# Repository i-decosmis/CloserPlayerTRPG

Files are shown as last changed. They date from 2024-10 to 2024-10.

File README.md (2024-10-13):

# CloserPlayerTRPG

<div align="center">

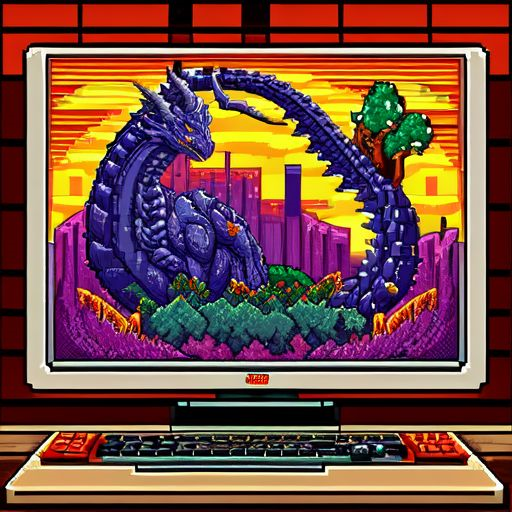
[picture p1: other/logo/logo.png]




</div>

# Introduction 🐉
This project aims to reduce the feeling of remoteness for people playing hybrid TRPGs online (some players in person and one online for now).
The basic idea is giving the remote player the opportunity to easily interact with the environment during the session.

The idea is to use a `client-server` application to remotely control a rotating platform, where a portable computer or tablet can be placed to display the remote player. 
The remote player can control the rotating platform from their computer. 
This concept is based on using a video-call communication app like Discord. 
This way, the remote player can look around and interact more effectively with others, while the in-person players can see his face throughout the session.

# Introduzione 🐉
Questo progetto mira a ridurre la sensazione di lontananza per le persone che giocano a TRPG ibridi online (con alcuni giocatori in presenza e uno online per ora).

L'idea di base è offrire al giocatore remoto la possibilità di interagire facilmente con l'ambiente durante la sessione.

L'idea è utilizzare un'applicazione client-server per controllare a distanza una piattaforma rotante, su cui può essere posizionato un computer portatile o un tablet per mostrare il giocatore remoto. Il giocatore remoto può controllare la piattaforma rotante dal proprio computer. Questo concetto si basa sull'uso di un'app di comunicazione video come Discord. In questo modo, il giocatore remoto può guardarsi intorno e interagire in modo più efficace con gli altri, mentre i giocatori in presenza possono vedere il suo volto per tutta la durata della sessione.

- [English version](guide/en/README.md)
- [Versione italiana](guide/it/README.md)

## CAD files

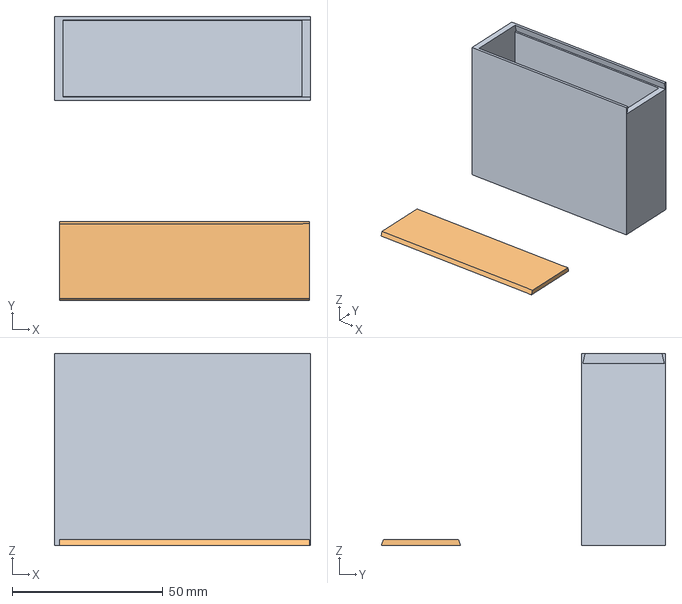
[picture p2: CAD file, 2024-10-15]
other/3D pieces/box.3mf
85.0 x 94.4 x 63.8 mm
box.stl
lid.stl

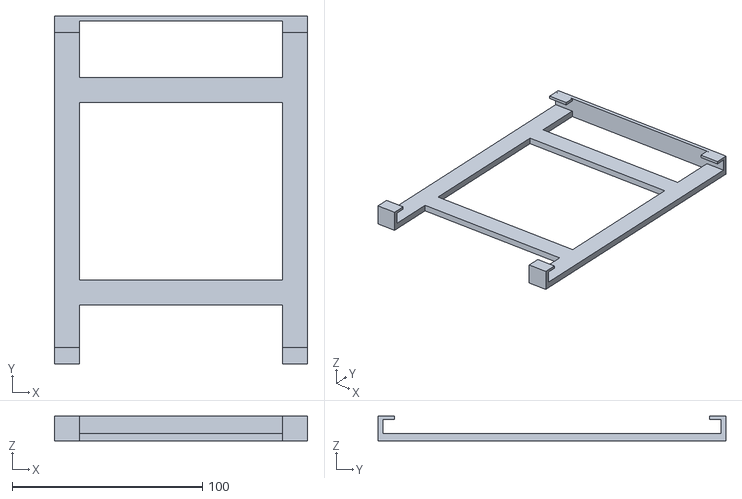
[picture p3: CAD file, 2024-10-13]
other/3D pieces/Structure.stl
133.1 x 183.1 x 13.0

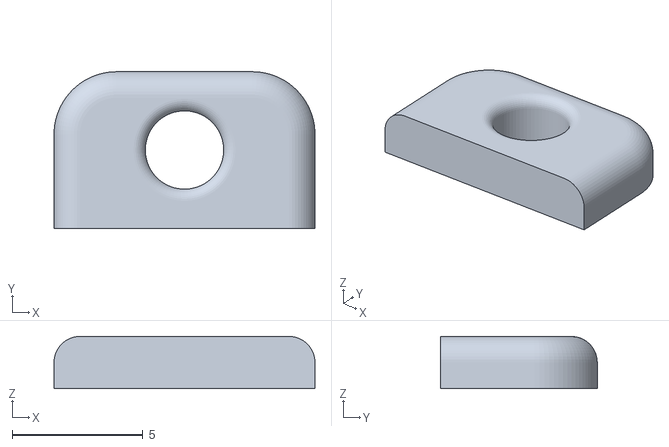
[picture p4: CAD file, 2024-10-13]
other/3D pieces/BoltHole.stl
10.0 x 6.00 x 2.00

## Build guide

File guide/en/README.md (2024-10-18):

# The basic architecture 🏗️
The server, placed on top of the rotating platform, will interact with an Arduino. This Arduino will control the platform's rotation.
The client will be used by the remote player to control the rotating platform.

# Software 💿

## Installation of Requirements 🔧
* Install Anaconda.
* Navigate in the `other/utils` folder.
* Run the following command: 
```bash
conda env create --file environment.yml --name CloserPlayerTRPG
```
* At the end of the installation activate the environment:
```bash
conda activate CloserPlayerTRPG
```

# Use the framework 📙
To use the framework, you can run the file directly from the console or generate an .exe file and run the generated executable.
## Run from console ⌨️
* Navigate in the `app` folder.
### Client 🖥️
* Navigate in the `client` folder.
* Run:
```bash
python client.py
```
### Server 🌐
* Navigate in the `server` folder.
* Run:
```bash
python server.py
```

## Exporting app for Windows
### Client 🖥️
* Navigate in the `app/client` folder.
* Run the following command:
```bash
pyinstaller --onefile --windowed client.py
```
* In the dist folder you can find the exe file of the client.

### Server 🌐
* Navigate in the `app/server` folder.
* Run the following command:
```bash
pyinstaller --onefile --windowed server.py
```
* In the dist folder you can find the exe file of the server.

# Hardware  🛠️
## Components used: 🎟️
* [Mcbazel - 360° Rotating Stand](https://www.amazon.it/dp/B09FZ36N3M?ref=ppx_yo2ov_dt_b_fed_asin_title).
* [Arduino Nano Clone](https://www.amazon.it/dp/B0CWH4P152?ref=ppx_yo2ov_dt_b_fed_asin_title).
* [Breadboard](https://www.amazon.it/dp/B078HV79XX?ref=ppx_yo2ov_dt_b_fed_asin_title).

## Steps 📋
### Adapting the Rotating Stand
* Remove the top lid:
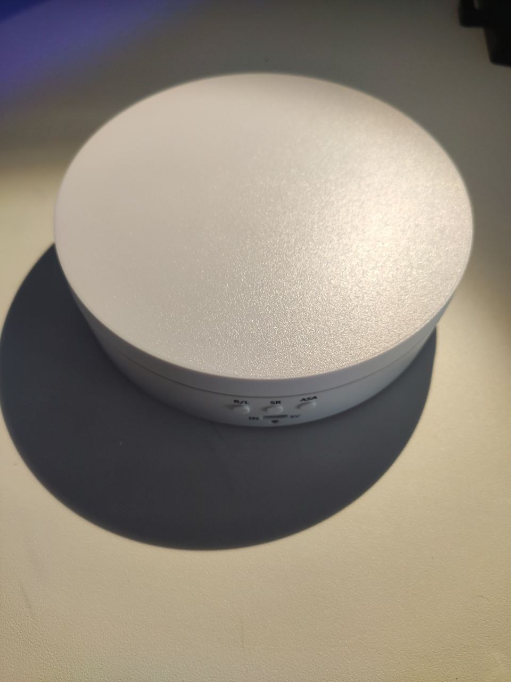
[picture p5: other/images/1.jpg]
One

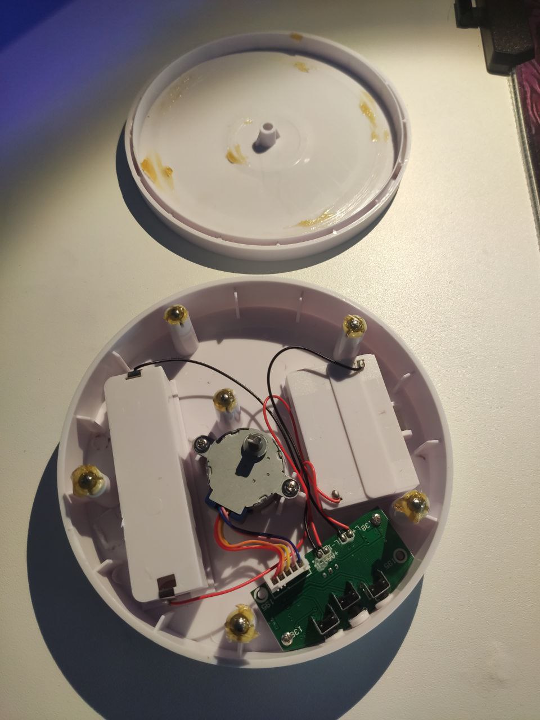
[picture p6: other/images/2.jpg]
Two


* Unplug the motor from the motherboard.
* Remove the motor and motherboard from the case, and cut the wires connected to the battery holders:
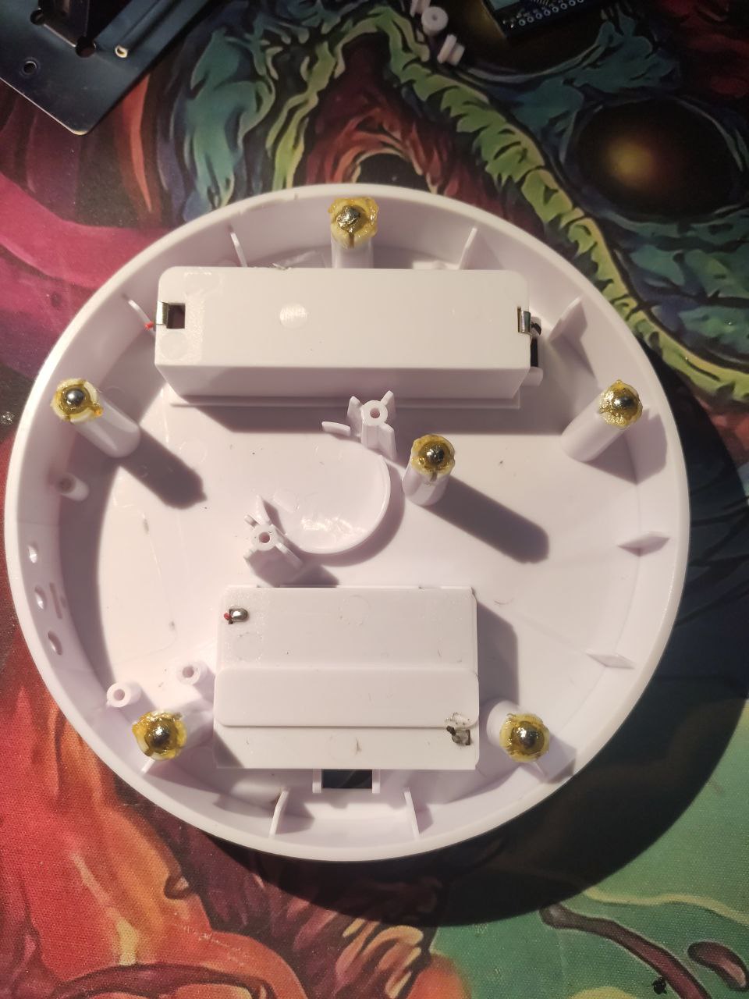
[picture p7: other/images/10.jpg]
Ten

* Cut the battery holders to create more space inside the case. I used my soldering iron for this:
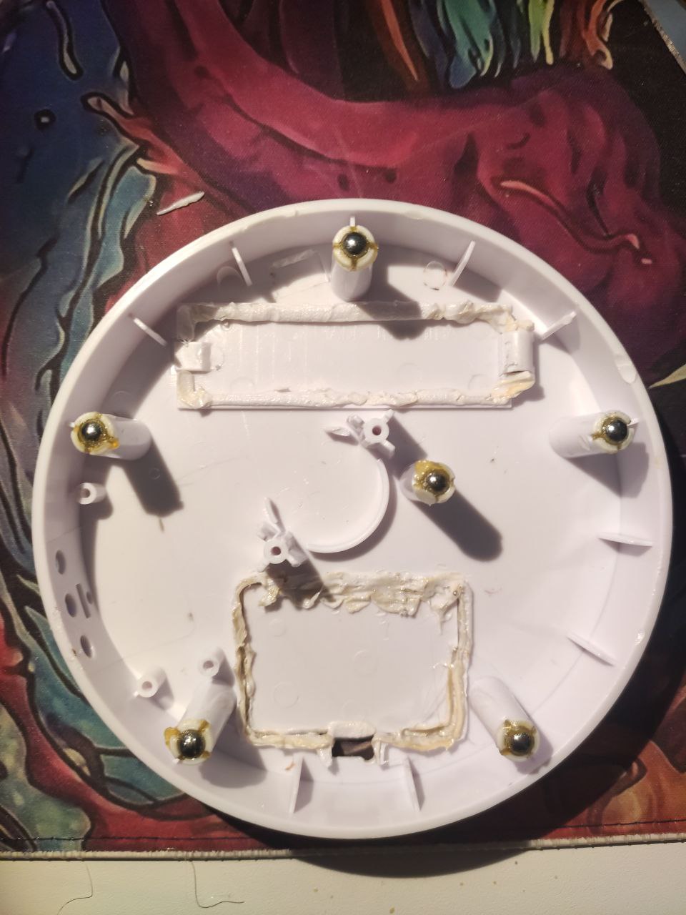
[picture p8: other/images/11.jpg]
Eleven


### Remove the useful components from the motherboard

* Cut the ULN2003 component and desolder the motor connector:
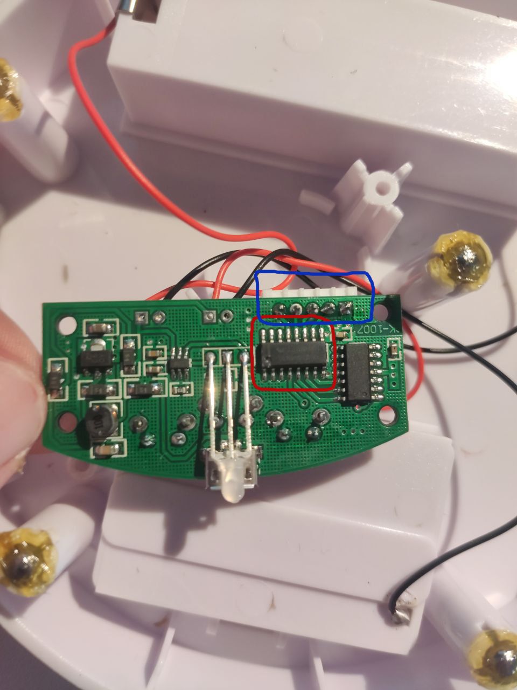
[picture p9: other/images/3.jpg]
Three

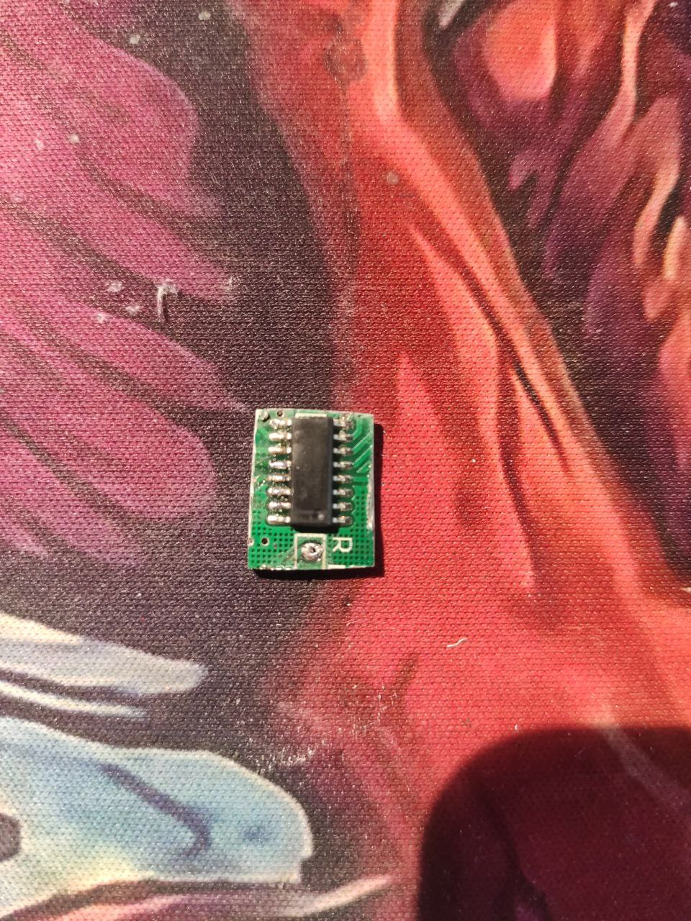
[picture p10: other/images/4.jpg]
Four


* Use double-sided tape to attach the removed component to the breadboard:
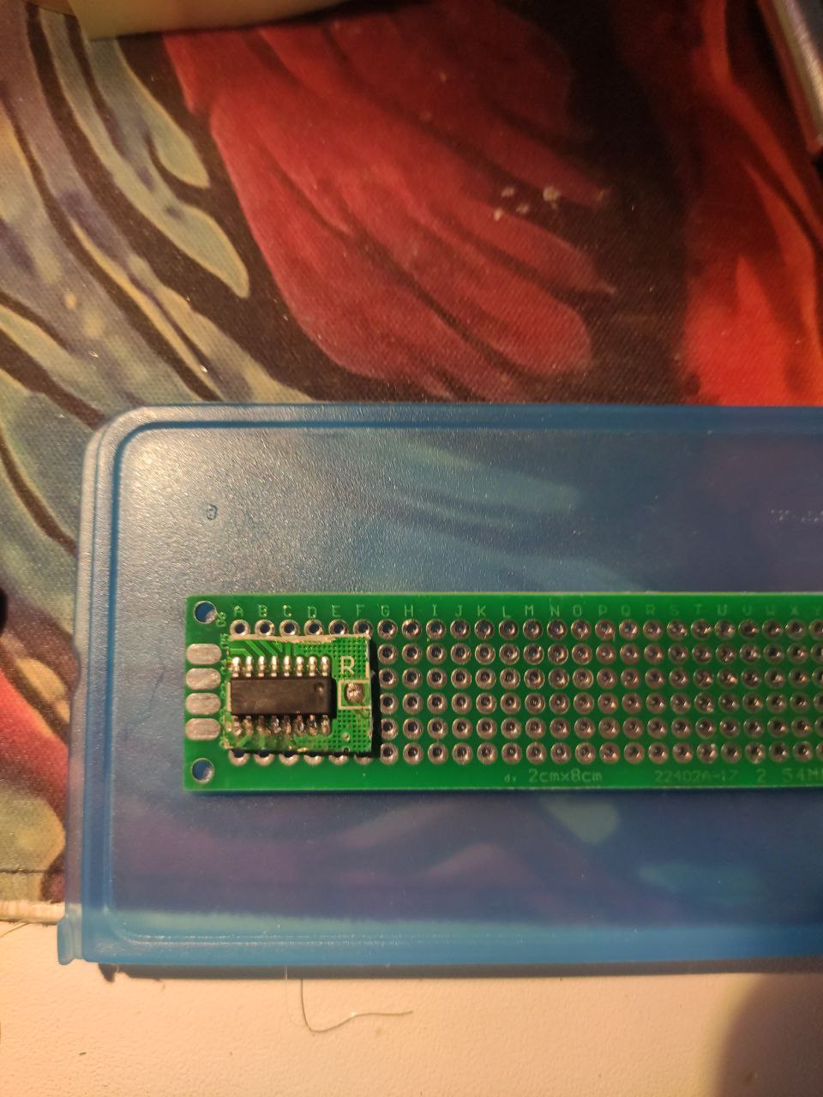
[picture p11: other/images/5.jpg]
Five


* Use a soldering iron to connect the ULN2003 to the motor connector, referring to the following schematic for guidance:
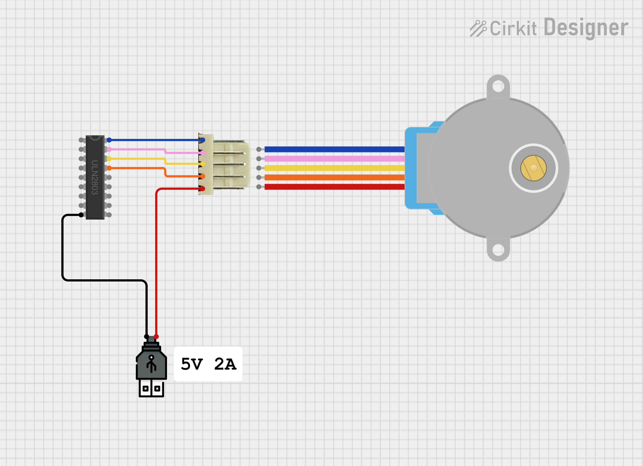
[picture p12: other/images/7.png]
Six

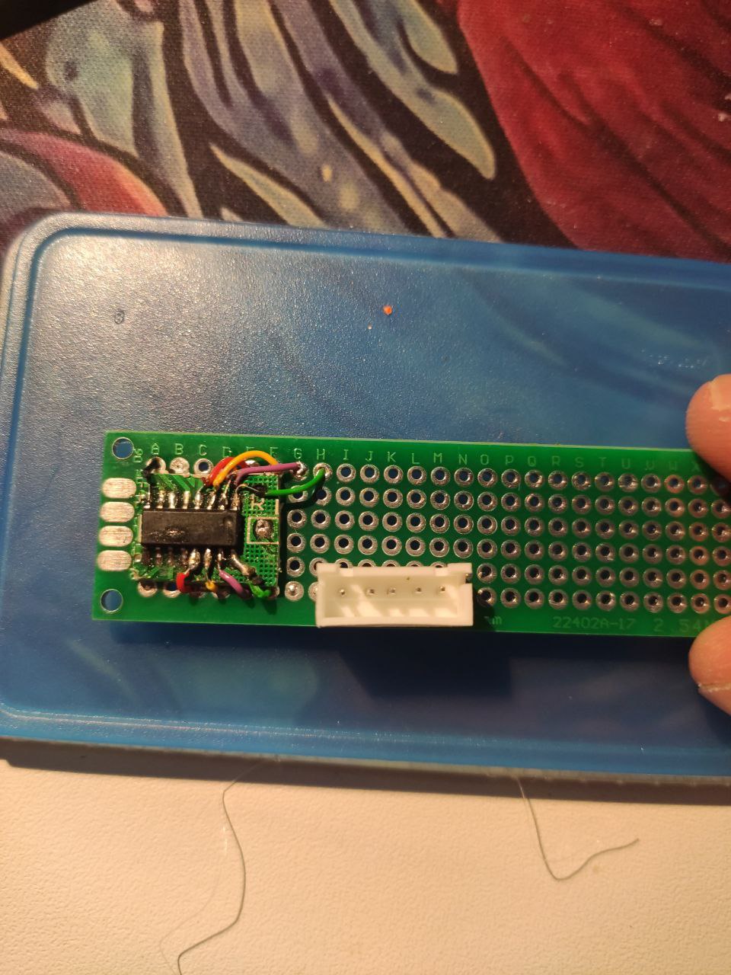
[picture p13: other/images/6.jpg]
Seven


* Use a soldering iron to connect the Arduino Nano to the ULN2003, referring to the following schemaric for guidance:
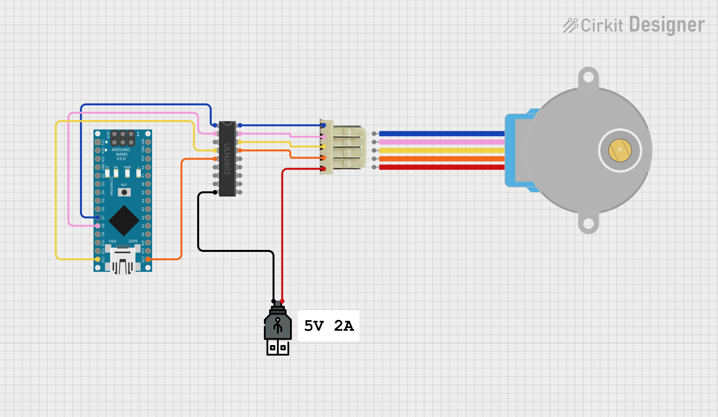
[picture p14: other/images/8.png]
Eight

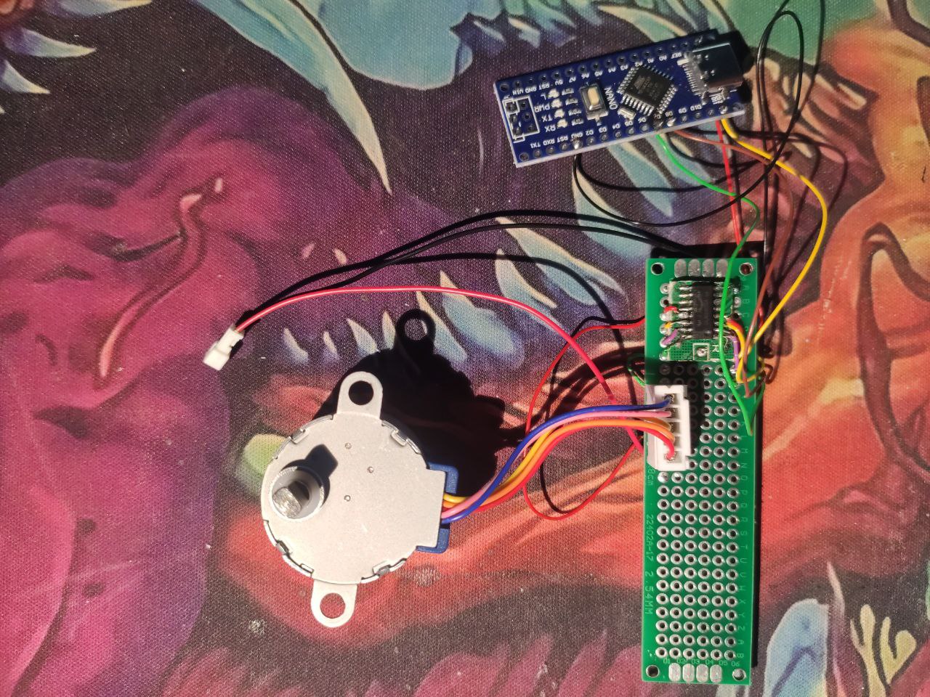
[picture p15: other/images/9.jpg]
Nine


* I inserted the components as shown in the image, using hot glue to fix them in place and using a male/female connector to be able to disconnect the 5V USB power supply if necessary:
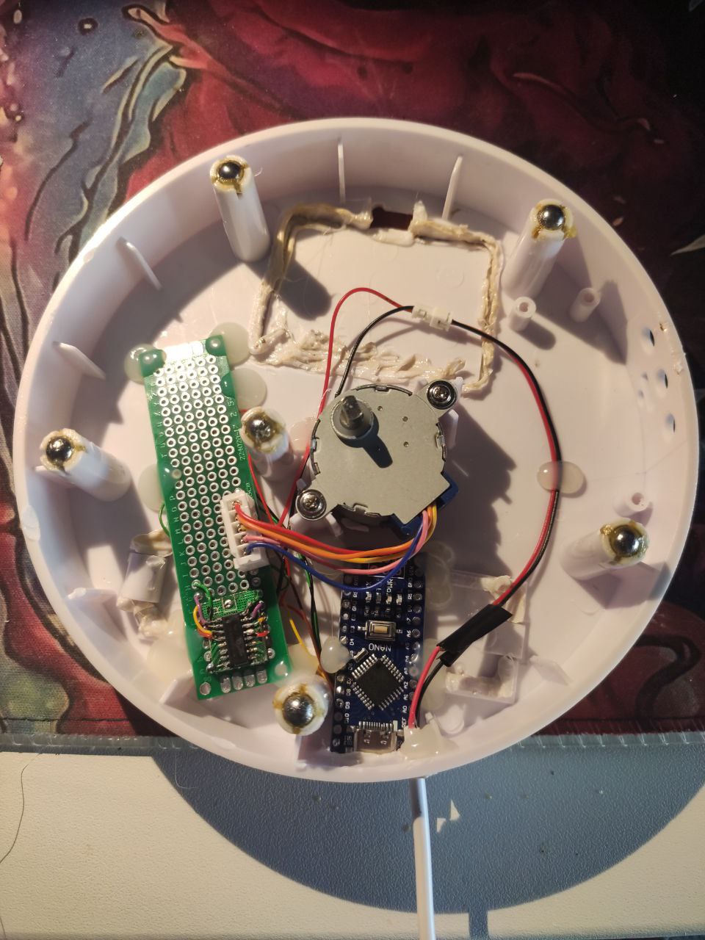
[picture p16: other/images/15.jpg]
Fifteen


### 3D print a tablet holder (optional)
* You can also use a portable PC, but for practical reasons, I chose to use a tablet. Therefore, I needed a structure to hold it.
The following models are available:
    * [Structure to hold the tablet](../../other/3D%20pieces/Structure.stl)
    * [Bolt holes](../../other/3D%20pieces/BoltHole.stl)

I've fused the two pieces togheter using a cyanoalicrate based glue.

* Results:
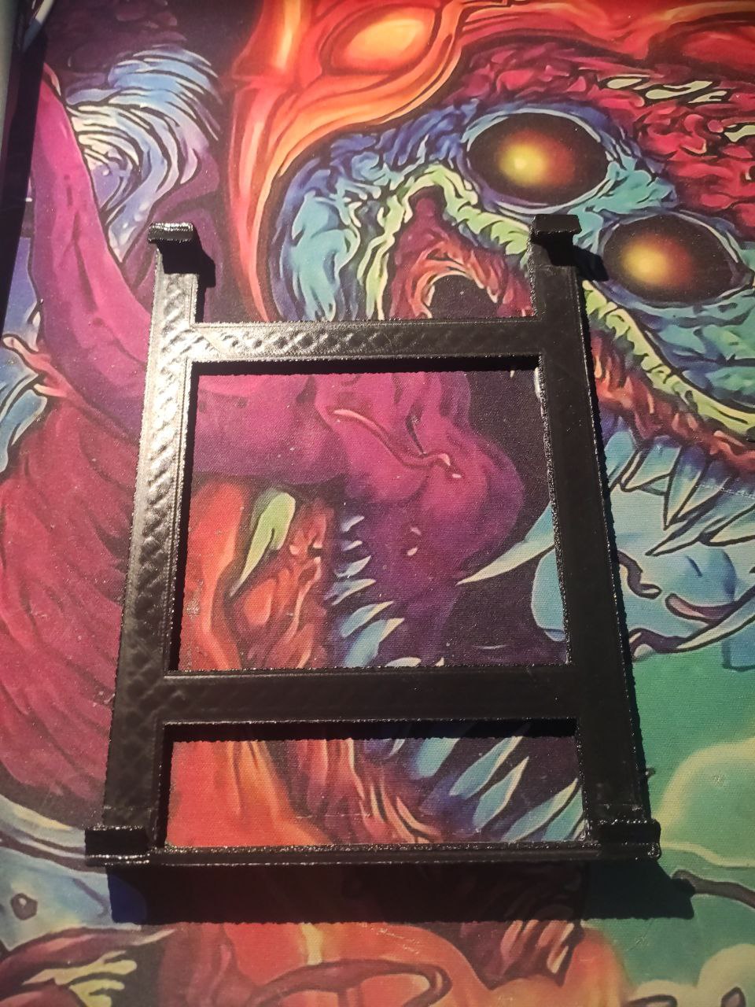
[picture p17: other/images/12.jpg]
Twelve

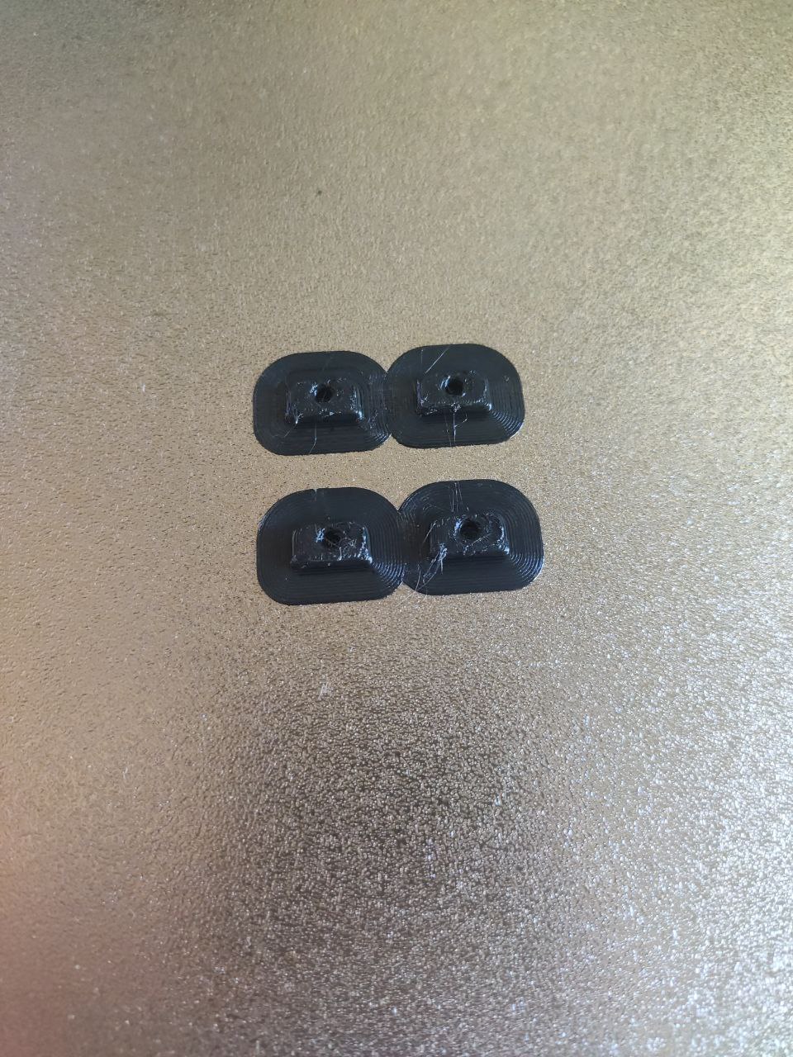
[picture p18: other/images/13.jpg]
Thirteen


* Using the iron solder I punctured the plate and with 4 bolts I connected the two pieces:
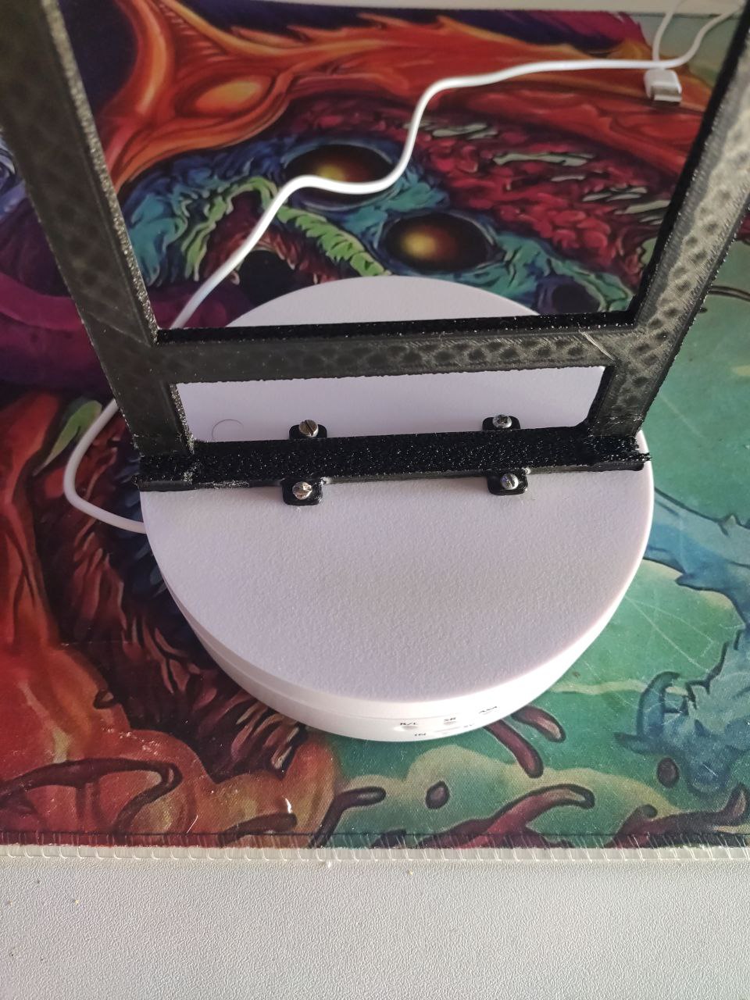
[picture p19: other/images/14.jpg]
Fourthen


### Final result
* Slide the tablet in the frame.
* I have used an externa webcam with integrated mic, I have also used a usb-c hub, hotglued to the back of the plane, to connet the cam and arduino to the tablet as show in the figures:
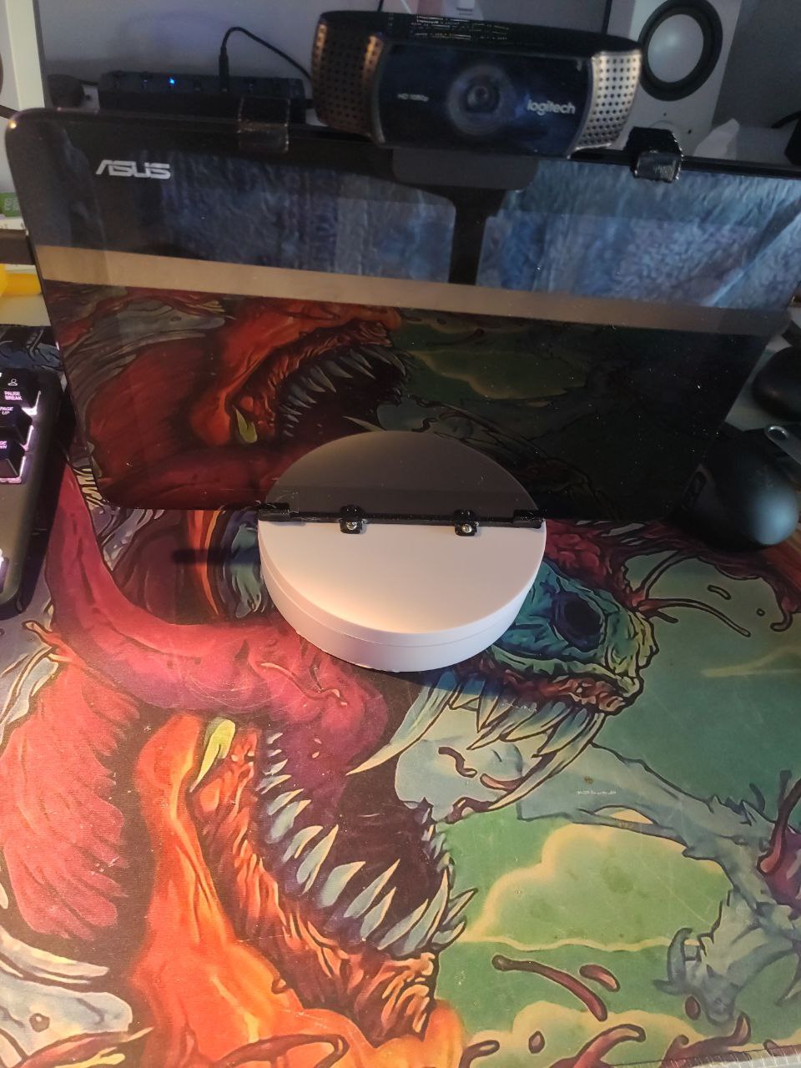
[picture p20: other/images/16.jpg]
Sixteen

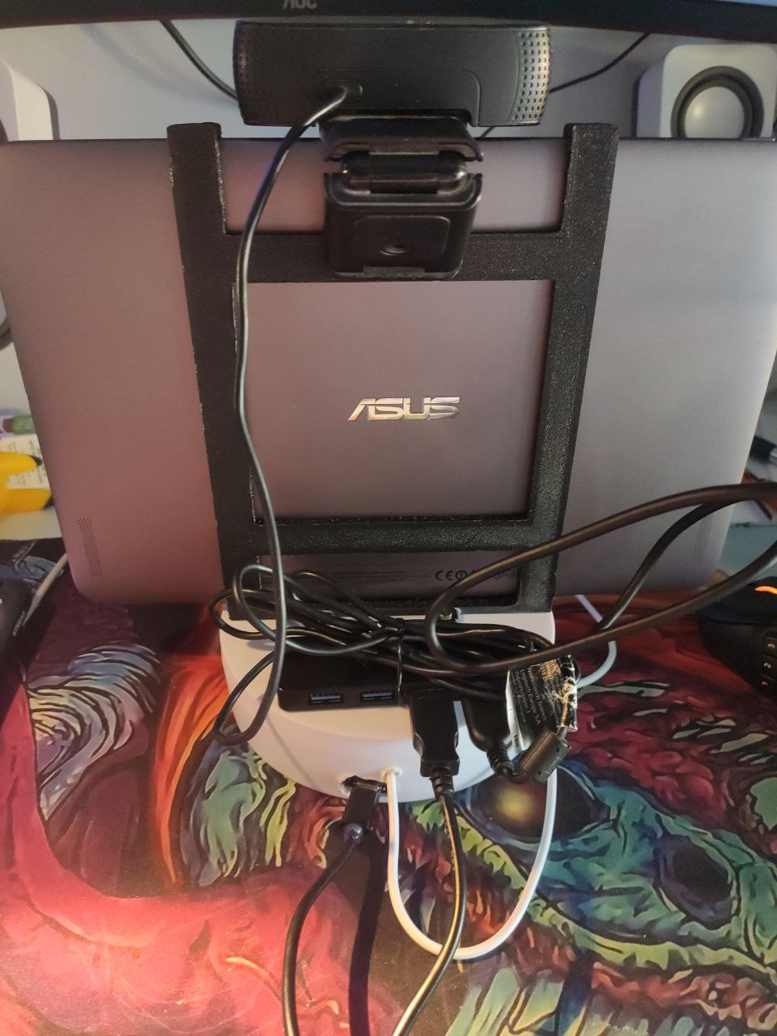
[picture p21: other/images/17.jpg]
Seventeen

This general schema represent the final result:
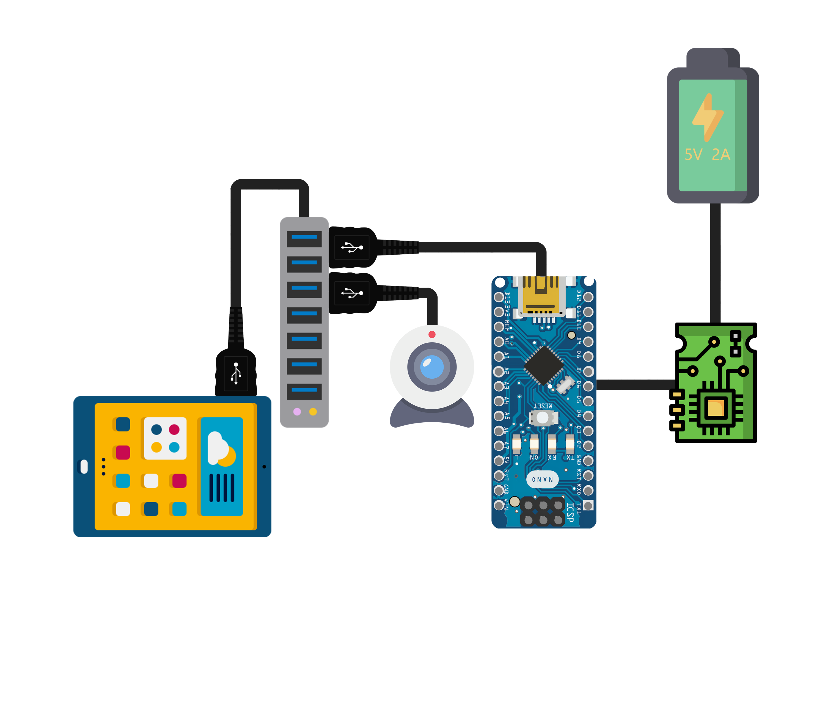
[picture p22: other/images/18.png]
Eighteen


### Improvements 📈
This improvements are optional but allow for a better cable management and practicality:
* I have 3d printed a [small box](../../other/3D%20pieces/box.3mf) to store all the cables inside.
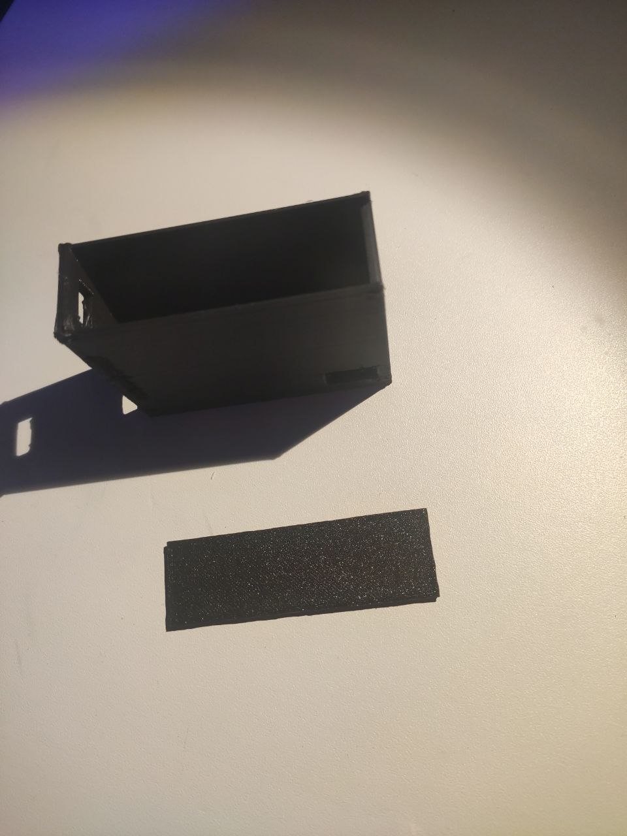
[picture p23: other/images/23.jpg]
Twentythree

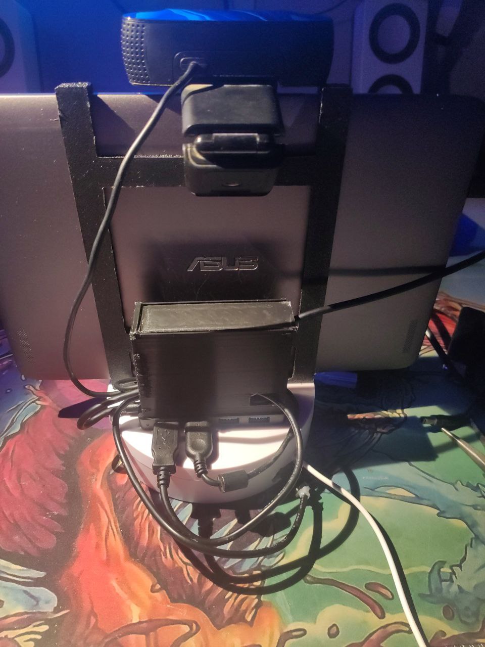
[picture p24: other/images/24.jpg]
Twentyfour


* My tablet can't stay on for the entire session, so it needs to be charged. To avoid adding more cables, I decided to change the power supply by using a [multi-USB 5V charger with two outputs rated at 5V and 3.1A](https://www.amazon.it/dp/B0D73DZ6QT?ref=ppx_yo2ov_dt_b_fed_asin_title). I soldered the two USB outputs together to power both the 28BYJ-48 motor and the tablet with a single cable.
* Updated general circuit:
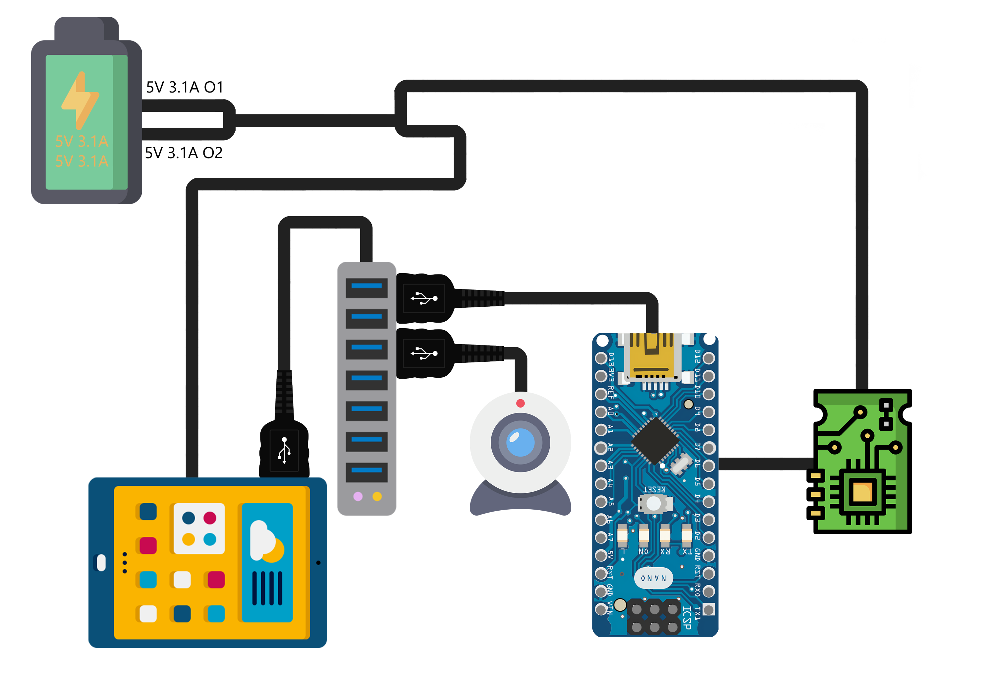
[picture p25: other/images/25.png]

Note: In my case, the tablet also needed the data pins to be connected, even though the cable is only used for charging.

* To achieve a cleaner front appearance, I also added a 90-degree connector to the USB-C hub and another 90-degree connector for the tablet's charging port.
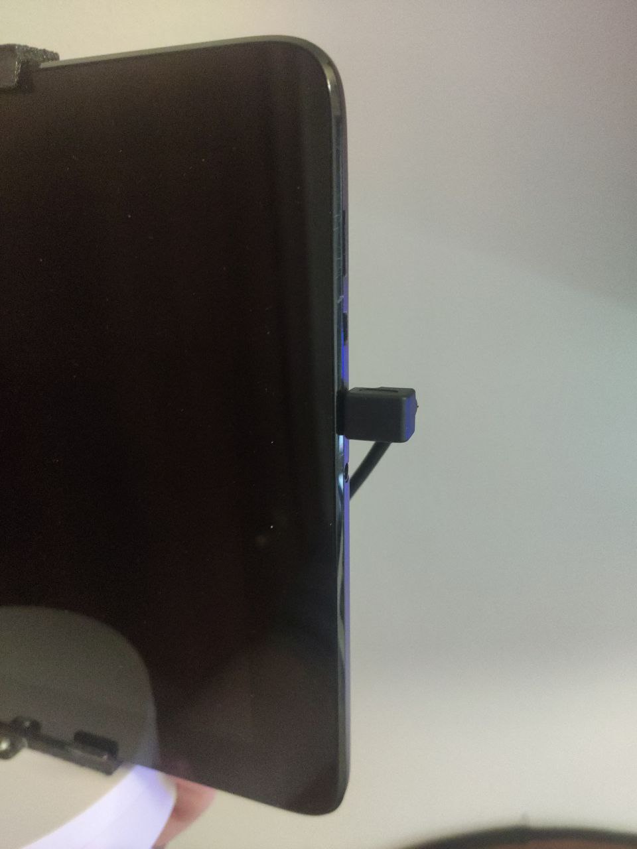
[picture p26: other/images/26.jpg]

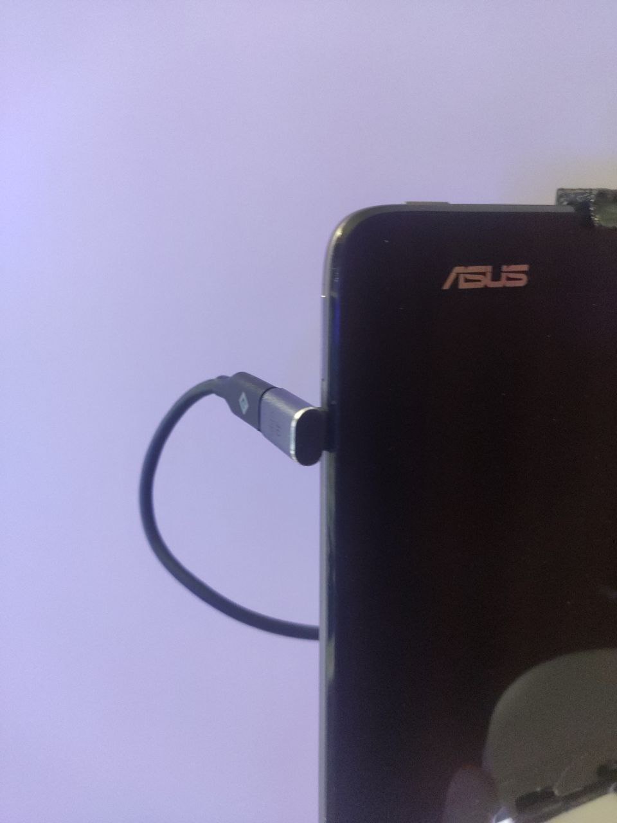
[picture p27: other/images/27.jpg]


# User Guide 📜
## Server 🌐
* Open the server.
* Insert the Ip Address and the port where to host the server, e.g. `127.0.0.1:5556`.
* Select in the top right the comunication port for arduino.
* Click `Start Server`.
* Wait for the client to connect.

## Client 🖥️
* Open the client.
* Insert the Ip Address and the port, e.g. `127.0.0.1:5556`.
* Click `Connect`.
* Once connected, the window will resize to a small frame where the selected input will be displayed.
* To send input, you must select the window first. If other applications are selected, the client will not detect the input.

## Router port ❌
To avoid opening router ports, use app like Tailscale or Hamachi.

### Example with Hamachi
* On the server pc:
    * Open Hamachi 
    * Create a new network, e.g. `CloserTest`:
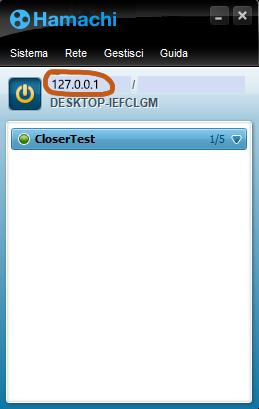
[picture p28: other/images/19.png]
Nineteen
    

    * Open the server application
    * Insert the highlighted Ip from your Hamachi and a port of your choise, e.g. `5556`.
    * Select on the top right the comunication port of the connected arduino:
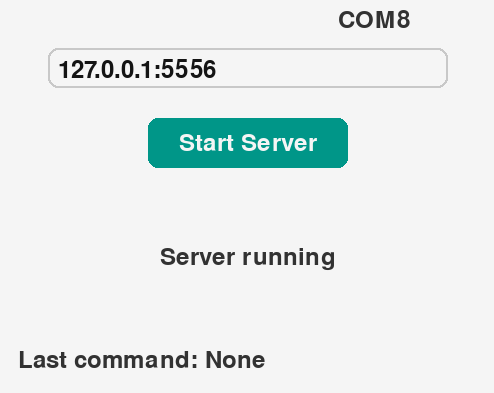
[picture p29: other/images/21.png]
Twentyone
    
    
    * Click `Start Server`
* On the client pc:
    * Open Hamachi.
    * Join the created network.
    * Open the client application.
    * Insert the Ip of the server pc and the port you choose during the server start (In this example `127.0.0.1:5556`).
    * Click `Connect`.
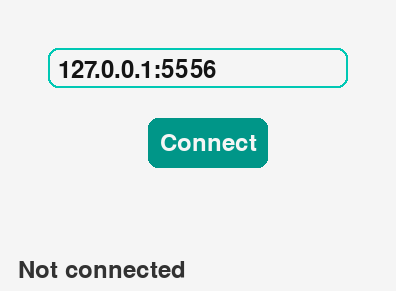
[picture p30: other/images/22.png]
Twentytwo
    

Now you can control the rotation of the arduino connected to the server with the client.
Using a voice chat app (like Discord), your friend playing remotely can move the tablet and look around, while everyone playing in person can see his face as he looks around!

# Issues 🆘
Nothing for now

# Future Ideas 💡
* Provide the remote player with the opportunity to physically roll a die using a robotic hand.
* Create "dances" that the platform can perform to allow the player to celebrate after a funny situation.
* 3d print a structure for vertical rotation.

# License 🛂
This project is licensed under the **GNU General Public License v3.0**. You are free to use, modify, and distribute this code under the following conditions:

1. **Attribution**: If you use this code as a base for your project or create derivative works, please give appropriate credit by including my name (Ivan De Cosmis) in your project documentation, README, or other relevant materials.

2. **Share-Alike**: Any derivative work you create based on this project must also be licensed under the GPLv3. This ensures that future users can benefit from your modifications as well.

3. **Commercial Use**: If you intend to use this project or any derivatives for commercial purposes, please reach out to me first to discuss proper attribution and any potential agreements.

For more details, please refer to the full text of the **GNU General Public License v3.0** [here](https://www.gnu.org/licenses/gpl-3.0.html).

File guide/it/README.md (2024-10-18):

# L'architettura di base 🏗️
Il server, posizionato sopra la piattaforma rotante, interagirà con un Arduino. Questo Arduino controllerà la rotazione della piattaforma.  
Il client sarà utilizzato dal giocatore remoto per controllare la piattaforma rotante.

# Software 💿

## Installazione dei requisiti 🔧
* Installa Anaconda.
* Vai nella cartella `other/utils`.
* Esegui il seguente comando:
```bash
conda env create --file environment.yml --name CloserPlayerTRPG
```
* Alla fine dell'installazione, attiva l'ambiente:
```bash
conda activate CloserPlayerTRPG
```

# Utilizzo del framework 📙
Per usare il framework, puoi eseguire il file direttamente dalla console o generare un file .exe ed eseguire l'eseguibile generato.
## Esecuzione da console ⌨️
* Vai nella cartella `app`.
### Client 🖥️
* Vai nella cartella `client`.
* Esegui:
```bash
python client.py
```
### Server 🌐
* Vai nella cartella `server`.
* Esegui:
```bash
python server.py
```

## Esportare l'app per Windows
### Client 🖥️
* Vai nella cartella `app/client`.
* Esegui il seguente comando:
```bash
pyinstaller --onefile --windowed client.py
```
* Nella cartella dist troverai il file exe del client.

### Server 🌐
* Vai nella cartella `app/server`.
* Esegui il seguente comando:
```bash
pyinstaller --onefile --windowed server.py
```
* Nella cartella dist troverai il file exe del server.

# Hardware 🛠️
## Componenti utilizzati 🎟️
* [Mcbazel - Supporto rotante a 360°](https://www.amazon.it/dp/B09FZ36N3M?ref=ppx_yo2ov_dt_b_fed_asin_title).
* [Arduino Nano Clone](https://www.amazon.it/dp/B0CWH4P152?ref=ppx_yo2ov_dt_b_fed_asin_title).
* [Breadboard](https://www.amazon.it/dp/B078HV79XX?ref=ppx_yo2ov_dt_b_fed_asin_title).

## Passaggi 📋
### Adattamento del supporto rotante
* Rimuovi il coperchio superiore:
Uno
Due

* Scollega il motore dalla scheda madre.
* Rimuovi il motore e la scheda madre dalla custodia e taglia i fili collegati ai porta batterie:
Dieci
* Taglia i porta batterie per creare più spazio all'interno della custodia. Ho usato il mio saldatore per questo:
Undici

### Rimuovere i componenti utili dalla scheda madre

* Taglia il componente ULN2003 e dissalda il connettore del motore:
Tre
Quattro

* Usa del nastro biadesivo per fissare il componente rimosso sulla breadboard:
Cinque

* Usa un saldatore per collegare l'ULN2003 al connettore del motore, facendo riferimento allo schema seguente per orientarti:
Sei
Sette

* Usa un saldatore per collegare l'Arduino Nano all'ULN2003, facendo riferimento allo schema seguente:
Otto
Nove

* Ho inserito i componenti come mostrato nell'immagine, utilizzando colla a caldo per fissarli e un connettore maschio/femmina per poter scollegare l'alimentatore USB da 5V se necessario:
Quindici

### Stampa 3D di un supporto per tablet (opzionale)
* Puoi anche usare un PC portatile, ma per motivi pratici ho scelto di usare un tablet. Di conseguenza, avevo bisogno di una struttura per sorreggerlo.  
I seguenti modelli sono disponibili:
    * [Struttura per sorreggere il tablet](../../other/3D%20pieces/Structure.stl)
    * [Fori per le viti](../../other/3D%20pieces/BoltHole.stl)

Ho unito i due pezzi usando una colla a base di cianoacrilato.

* Risultati:
Dodici
Tredici

* Usando il saldatore, ho forato la piastra e con 4 viti ho collegato i due pezzi:
Quattordici

### Risultato finale
* Inserisci il tablet nel supporto.
* Ho usato una webcam esterna con microfono integrato e un hub USB-C, incollato con la colla a caldo sul retro del piano, per collegare la webcam e l'Arduino al tablet, come mostrato nelle immagini:
Sedici
Diciassette  
Questo schema generale rappresenta il risultato finale:
Diciotto

### Miglioramenti 📈
Questi miglioramenti sono opzionali, ma consentono una migliore gestione dei cavi e praticità:
* Ho stampato in 3D una [piccola scatola](../../other/3D%20pieces/box.3mf) per conservare tutti i cavi all'interno.
Ventitré
Ventiquattro

* Il mio tablet non riesce a rimanere acceso per tutta la sessione, quindi deve essere caricato. Per evitare di aggiungere altri cavi, ho deciso di cambiare l'alimentatore utilizzando un [caricatore multi-USB da 5V con due uscite da 5V e 3,1A](https://www.amazon.it/dp/B0D73DZ6QT?ref=ppx_yo2ov_dt_b_fed_asin_title). Ho saldato insieme le due uscite USB per alimentare sia il motore 28BYJ-48 che il tablet con un unico cavo.
* Circuito generale aggiornato:
Twentyfive
Nota: Nel mio caso, il tablet aveva bisogno anche dei pin dati collegati, anche se il cavo è usato solo per la ricarica.
* Per ottenere un aspetto frontale più pulito, ho anche aggiunto un connettore a 90 gradi all'hub USB-C e un altro connettore a 90 gradi per la porta di ricarica del tablet.
Twentyfive
Twentyfive

# Guida utente 📜
## Server 🌐
* Apri il server.
* Inserisci l'indirizzo IP e la porta su cui ospitare il server, es. `127.0.0.1:5556`.
* Seleziona in alto a destra la porta di comunicazione per Arduino.
* Clicca su `Start Server`.
* Attendi che il client si connetta.

## Client 🖥️
* Apri il client.
* Inserisci l'indirizzo IP e la porta, es. `127.0.0.1:5556`.
* Clicca su `Connect`.
* Una volta connesso, la finestra si ridimensionerà a un piccolo frame in cui verrà visualizzato l'input selezionato.
* Per inviare input, devi prima selezionare la finestra. Se sono selezionate altre applicazioni, il client non rileverà l'input.

## Porta del router ❌
Per evitare di aprire le porte del router, usa app come Tailscale o Hamachi.

### Esempio con Hamachi
* Sul PC server:
    * Apri Hamachi.
    * Crea una nuova rete, es. `CloserTest`:
    Diciannove

    * Apri l'applicazione server.
    * Inserisci l'IP evidenziato da Hamachi e una porta a tua scelta, es. `5556`.
    * Seleziona in alto a destra la porta di comunicazione di Arduino collegato:
    Ventuno
    
    * Clicca su `Start Server`.
* Sul PC client:
    * Apri Hamachi.
    * Unisciti alla rete creata.
    * Apri l'applicazione client.
    * Inserisci l'IP del PC server e la porta scelta durante l'avvio del server (in questo esempio `127.0.0.1:5556`).
    * Clicca su `Connect`.
    Ventidue

Ora puoi controllare la rotazione dell'Arduino collegato al server con il client. Utilizzando un'app di chat vocale (come Discord), il tuo amico che gioca da remoto può muovere il tablet e guardarsi intorno, mentre tutti i giocatori in presenza possono vedere il suo volto mentre si guarda attorno!

# Problemi 🆘
Nessuno per ora.

# Idee future 💡
* Fornire al giocatore remoto la possibilità di lanciare fisicamente un dado usando una mano robotica.
* Creare "danze" che la piattaforma può eseguire per permettere al giocatore di festeggiare dopo una situazione divertente.
* Stampare in 3D una struttura per la rotazione verticale.

# Licenza 🛂
Questo progetto è concesso sotto licenza **GNU General Public License v3.0**. Sei libero di usare, modificare e distribuire questo codice alle seguenti condizioni:

1. **Attribuzione**: Se usi questo codice come base per il tuo progetto o crei opere derivate, ti preghiamo di dare credito appropriato includ

endo il mio nome (Ivan De Cosmis) nella documentazione del tuo progetto, README o altri materiali rilevanti.

2. **Condivisione allo stesso modo**: Qualsiasi lavoro derivato che crei basato su questo progetto deve essere concesso in licenza sotto GPLv3. Questo assicura che gli utenti futuri possano beneficiare delle tue modifiche.

3. **Uso commerciale**: Se intendi usare questo progetto o qualsiasi derivato per scopi commerciali, contattami prima per discutere la corretta attribuzione e eventuali accordi.

Per maggiori dettagli, consulta il testo completo della **GNU General Public License v3.0** [qui](https://www.gnu.org/licenses/gpl-3.0.html).

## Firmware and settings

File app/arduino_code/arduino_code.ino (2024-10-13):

int IN1 = 7;
int IN2 = 8;
int IN3 = 12;
int IN4 = 13;
int speed = 1185;

// Sequenza di passi per il motore passo-passo
int steps[8][4] = {
  {1, 0, 0, 0},
  {1, 1, 0, 0},
  {0, 1, 0, 0},
  {0, 1, 1, 0},
  {0, 0, 1, 0},
  {0, 0, 1, 1},
  {0, 0, 0, 1},
  {1, 0, 0, 1}
};

char lastCommand = 'z';
bool isRunning = false;  // Variabile per tenere traccia se il motore è in esecuzione
char currentDirection = 'R';  // Direzione corrente del motore ('R' o 'L')

void setup() {
  Serial.begin(9600);  // Set serial communication to 9600 baud rate
  // Imposta i pin come uscite
  pinMode(IN1, OUTPUT);
  pinMode(IN2, OUTPUT);
  pinMode(IN3, OUTPUT);
  pinMode(IN4, OUTPUT);
}

void loop() {
  // Controlla se ci sono nuovi comandi dalla seriale
  if (Serial.available() > 0) {
    char command = Serial.read();  // Legge il comando

    // Se il comando è 'R', imposta il motore per girare a destra
    if (command == 'R') {
      if (lastCommand != command) {
        lastCommand = command;
        currentDirection = 'R';
        isRunning = true;  // Attiva il motore
      }
    }
    // Se il comando è 'L', imposta il motore per girare a sinistra
    else if (command == 'L') {
      if (lastCommand != command) {
        lastCommand = command;
        currentDirection = 'L';
        isRunning = true;  // Attiva il motore
      }
    }
    // Se il comando è un numero (1-9), cambia la velocità
    else if (isdigit(command)) {  
      speed = 723 + ((command - '0') * 77);
    }
    // Se il comando è 'S', ferma il motore
    else if (command == 'S') {
      isRunning = false;  // Ferma il motore
      lastCommand = command;
    }
  }

  // Se il motore è attivo, esegui il movimento nella direzione corrente
  if (isRunning) {
    if (currentDirection == 'R') {
      right();
    } else if (currentDirection == 'L') {
      left();
    }
  }
}

// Funzione per muovere il motore in avanti
void right() {
  for (int j = 0; j < 8; j++) {
    digitalWrite(IN1, steps[j][0]);
    digitalWrite(IN2, steps[j][1]);
    digitalWrite(IN3, steps[j][2]);
    digitalWrite(IN4, steps[j][3]);
    delayMicroseconds(speed);  // Imposta il ritardo tra i passi
  }
}

// Funzione per muovere il motore all'indietro
void left() {
  for (int j = 7; j >= 0; j--) {
    digitalWrite(IN1, steps[j][0]);
    digitalWrite(IN2, steps[j][1]);
    digitalWrite(IN3, steps[j][2]);
    digitalWrite(IN4, steps[j][3]);
    delayMicroseconds(speed);  // Imposta il ritardo tra i passi
  }
}

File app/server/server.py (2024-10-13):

# This file is part of CloserPlayerTRPG.
#
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
import zmq
import serial
import time
import threading
import pygame
import sys
from serial.tools import list_ports


# Function to read from the serial port
def read_from_serial():
    while True:
        if arduino.in_waiting > 0:
            line = arduino.readline().decode('utf-8').rstrip()
            print(f"Message from Arduino: {line}")

# Function to list available serial ports
def get_serial_ports():
    ports = list_ports.comports()
    return [port.device for port in ports]

serial_ports = get_serial_ports()  # List of available ports
selected_port = None  # User-selected port
show_ports = False  # Flag to show/hide the port selection menu


# Function to start the ZMQ server
def start_server(ip_address):
    global server_running, oldMessage

    try:
        # Create the ZeroMQ context
        context = zmq.Context()

        # Create a REQ/REP type socket
        socket = context.socket(zmq.REP)
        socket.bind(f"tcp://{ip_address}")

        print(f"Server listening on {ip_address}...")

        # Start a thread to read from the serial port
        threading.Thread(target=read_from_serial, daemon=True).start()

        while server_running:
            try:
                message = socket.recv_string(flags=zmq.NOBLOCK)  # Non-blocking, constantly checking
                if message != oldMessage:
                    oldMessage = message
                    update_last_command(message)  # Update the interface
                    if message.isnumeric():
                        print(f"Speed updated to: {message}")
                    else:
                        print(f"Command received: {message}")

                if message == "right":
                    arduino.write(b'R')
                elif message == "left":
                    arduino.write(b'L')
                elif message.isdigit():  # If we receive a number, we consider it as speed
                    arduino.write(message.encode())  # Send the number as a string to Arduino
                elif message == "S":
                    arduino.write(b'S')
                elif message == "exit":
                    break
                else:
                    socket.send_string("Unrecognized command")
                socket.send_string(f"Command '{message}' received")
            except zmq.Again:  # No messages available
                pass

        arduino.close()
        socket.close()
        context.term()
        print("Server closed.")
    except Exception as e:
        print(f"Error: {e}")

# Update the last received command on the interface
def update_last_command(command):
    global last_command
    last_command = command

# Initialize Pygame
pygame.init()

# Set up the Pygame window
screen = pygame.display.set_mode((500, 400))
pygame.display.set_caption("Arduino Control Server")

# Define some minimal style colors
WHITE = (245, 245, 245)
BLACK = (20, 20, 20)
LIGHT_GRAY = (200, 200, 200)
GRAY = (170, 170, 170)
DARK_GRAY = (50, 50, 50)
ACCENT_COLOR = (0, 150, 136)  # Primary color for buttons (teal)
ACTIVE_COLOR = (0, 200, 180)  # Border color when the field is active

# Set the font
font = pygame.font.Font(None, 36)

# Variables for the interface
input_box = pygame.Rect(50, 50, 400, 40)
ip_text = ''  # Text entered for the IP
start_button = pygame.Rect(150, 120, 200, 50)  # Button to start the server
stop_button = pygame.Rect(150, 190, 200, 50)  # Button to close the server
active_input = False  # Indicates whether the input field is active (focus)
server_running = False  # Indicates whether the server is active
last_command = "None"

# Function to draw the button
def draw_button(button_rect, text, active=False):
    """Draws a button in minimal style."""
    button_color = LIGHT_GRAY if active else ACCENT_COLOR
    pygame.draw.rect(screen, button_color, button_rect, border_radius=10)
    text_surface = font.render(text, True, WHITE)
    text_rect = text_surface.get_rect(center=button_rect.center)
    screen.blit(text_surface, text_rect)

# Function to draw the serial port selection menu
def draw_serial_port_menu():
    global show_ports, selected_port

    if selected_port:
        # If a port is selected, show the selected port and disable further selection
        selected_port_surface = font.render(f"{selected_port}", True, DARK_GRAY)
        screen.blit(selected_port_surface, (340, 10))
    else:
        # If no port is selected, show the "Select Port" button
        select_port_button = pygame.Rect(340, 10, 150, 30)
        pygame.draw.rect(screen, ACCENT_COLOR, select_port_button, border_radius=5)
        select_port_surface = font.render("Select Port", True, WHITE)
        screen.blit(select_port_surface, (select_port_button.x + 10, select_port_button.y + 5))

        # Toggle the port menu when the button is clicked
        if pygame.mouse.get_pressed()[0] and select_port_button.collidepoint(pygame.mouse.get_pos()):
            show_ports = True

    if show_ports and not selected_port:
        # Display the available ports as a list
        for i, port in enumerate(serial_ports):
            port_rect = pygame.Rect(340, 50 + i * 40, 150, 30)
            pygame.draw.rect(screen, LIGHT_GRAY, port_rect, border_radius=5)
            port_surface = font.render(port, True, BLACK)
            screen.blit(port_surface, (port_rect.x + 10, port_rect.y + 5))

            # Check if a port was clicked
            if pygame.mouse.get_pressed()[0] and port_rect.collidepoint(pygame.mouse.get_pos()):
                selected_port = port  # Store the selected port
                show_ports = False  # Hide the menu after selection



# Function to draw the interface
def draw_interface(mouse_pos):
    """Draws the graphical interface."""
    screen.fill(WHITE)
    
    # Draw the input box for the IP
    input_color = ACTIVE_COLOR if active_input else LIGHT_GRAY
    pygame.draw.rect(screen, input_color, input_box, border_radius=10, width=2)

    # Draw the text inside the input field
    txt_surface = font.render(ip_text, True, BLACK)
    screen.blit(txt_surface, (input_box.x + 10, input_box.y + 10))

    # Status message
    status_text = "Server running" if server_running else "Server not active"
    status_surface = font.render(status_text, True, DARK_GRAY)
    status_rect = status_surface.get_rect(center=(screen.get_width() // 2, 260))  # Center horizontally at y=260
    screen.blit(status_surface, status_rect)

    # Last command received
    last_command_surface = font.render(f"Last command: {last_command}", True, DARK_GRAY)
    screen.blit(last_command_surface, (20, 350))

    # Draw the buttons
    draw_button(start_button, "Start Server", active=start_button.collidepoint(mouse_pos))

    # Draw the serial port selection menu
    draw_serial_port_menu()

    pygame.display.flip()


# Main loop
running = True
arduino = None
oldMessage = -1
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

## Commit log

2024-10-10 Added arduino client and server
2024-10-10 Added arduino code
2024-10-10 Removed controller(uselles). Fixed timing for inputs from keyboards
    [arduino_client_keyboard.py, arduino_code.ino]
2024-10-13 Completed README, minor fix to server and client, added comunication port selection to the server. Added the 3D files.
    [BoltHole.stl, Structure.stl]
2024-10-15 Updated README with first improvement
    [box.3mf]
2024-10-15 Updated general circuit
2024-10-18 Fixed charging setup

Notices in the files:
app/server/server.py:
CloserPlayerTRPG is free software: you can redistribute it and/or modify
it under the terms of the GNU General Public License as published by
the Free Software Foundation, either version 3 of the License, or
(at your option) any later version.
